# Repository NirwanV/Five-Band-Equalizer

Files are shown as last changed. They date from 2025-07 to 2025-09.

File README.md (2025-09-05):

# 🎶 5-Band Analog Equalizer  
  
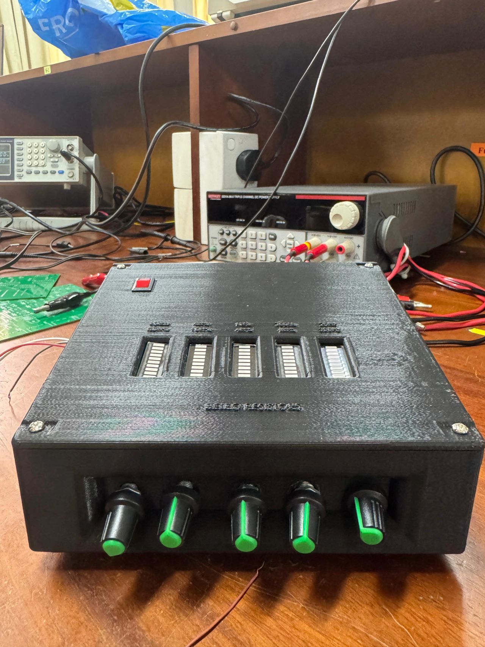
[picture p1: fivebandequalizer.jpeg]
CAD
  

A **5-Band Analog Audio Equalizer** built from scratch as part of an **Analog Design Project**.  
This project explores **audio signal processing using analog circuitry**, enabling users to shape and enhance sound across five distinct frequency bands.  

---

## ✨ Features  

- **5-Band Frequency Control**  
  - 60–300 Hz (Low)  
  - 300–1000 Hz (Low-Mid)  
  - 1–4 kHz (Mid)  
  - 4–10 kHz (High-Mid)  
  - 10–20 kHz (High)  

- **Precision Signal Processing**  
  - Buffered input audio  
  - Bandpass filtering for each frequency range  
  - Summed output for balanced and clean audio  

- **Audio Performance**  
  - Designed with **TL072 Op-Amps** for low-noise, high-fidelity sound  

- **User-Friendly Design**  
  - **LED indicators** for real-time band monitoring  
  - Custom **enclosure design** for a sleek, professional finish  

---

## 🛠️ Technologies & Tools  

- **Circuit Simulation & Design:** LTSpice / Multisim  
- **Prototyping:** Breadboard implementation  
- **PCB Design:** Altium Designer  
- **Enclosure Design:** SolidWorks / CAD tools  
- **Components:** TL072 Op-Amps, Resistors, Capacitors, Potentiometers, LEDs  

---

## 🚀 Getting Started  

1. **Build the Circuit** – Assemble the bandpass filters and buffering stages on a breadboard.  
2. **Test the Frequency Response** – Use a signal generator + oscilloscope to verify band cutoffs.  
3. **Integrate LED Indicators** – Connect LED driver circuit for real-time monitoring.  
4. **Assemble PCB & Enclosure** – Transfer the circuit to PCB and fit into the designed enclosure.  
5. **Enjoy Your Music!** 🎶  

---

## 📂 Repository Structure  

```bash
├── schematics/        # Circuit diagrams and LTSpice/Multisim files
├── pcb_layout/        # PCB design files (Altium)
├── enclosure/         # CAD models and renders
├── docs/              # Reports, notes, frequency response graphs
└── README.md          # Project documentation

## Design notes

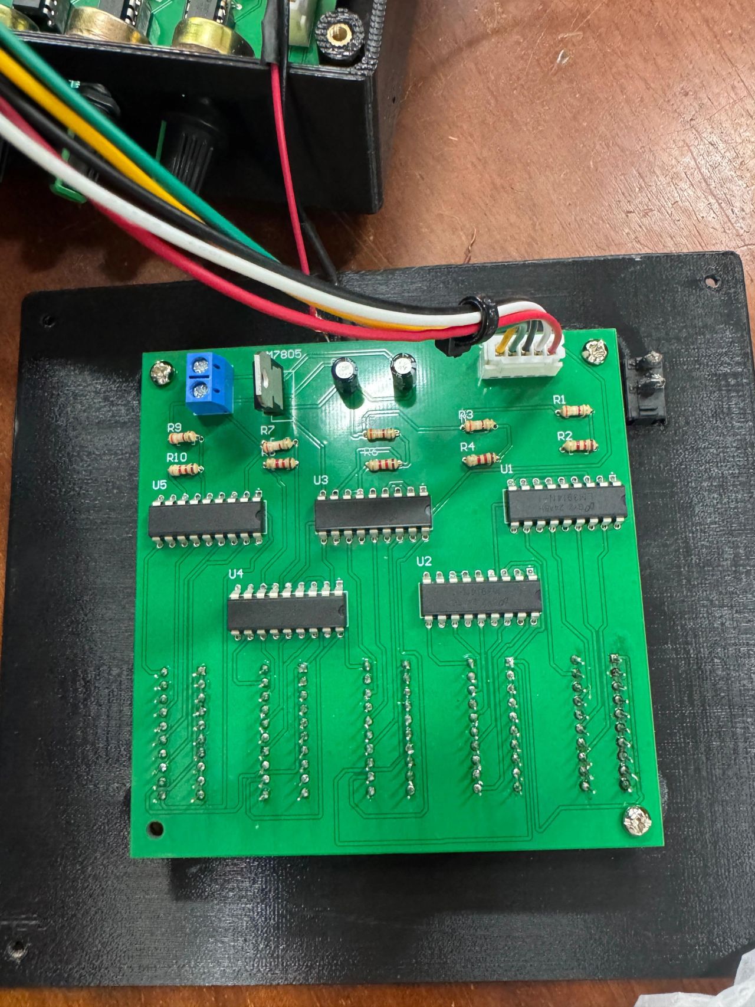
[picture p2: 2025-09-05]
LED_Bar_circuit_PCB.jpeg

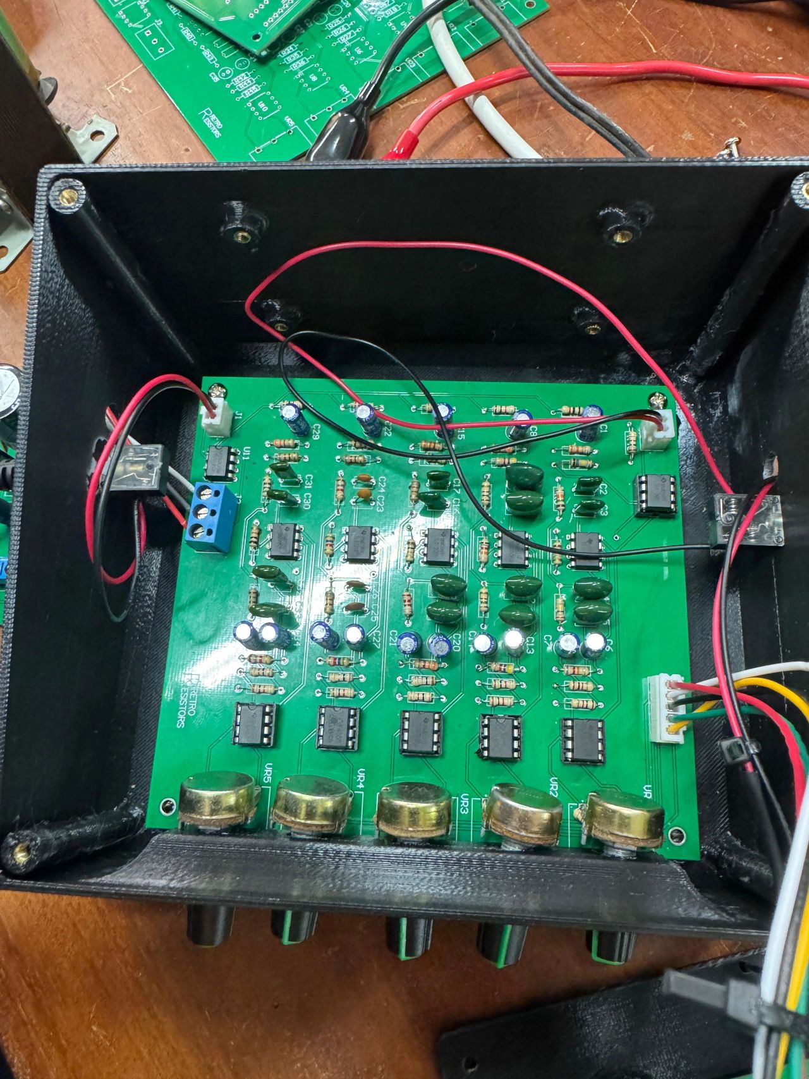
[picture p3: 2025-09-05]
FilterCircuitPCB.jpeg

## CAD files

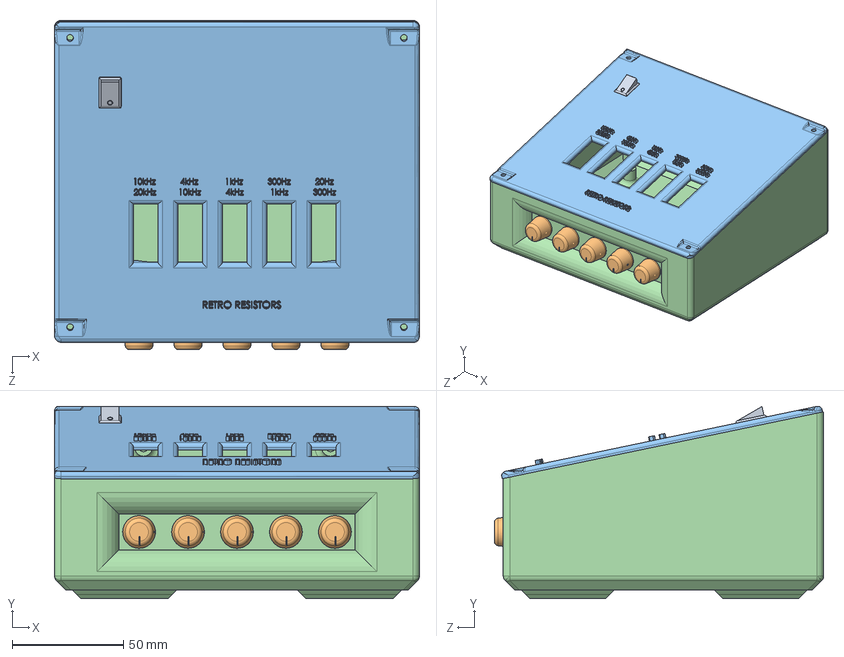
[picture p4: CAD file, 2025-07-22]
Version1/Solidworks/Assem1.11.SLDASM
164.0 x 86.5 x 148.0 mm
lab low
lab above
knob x 5
SWITCH

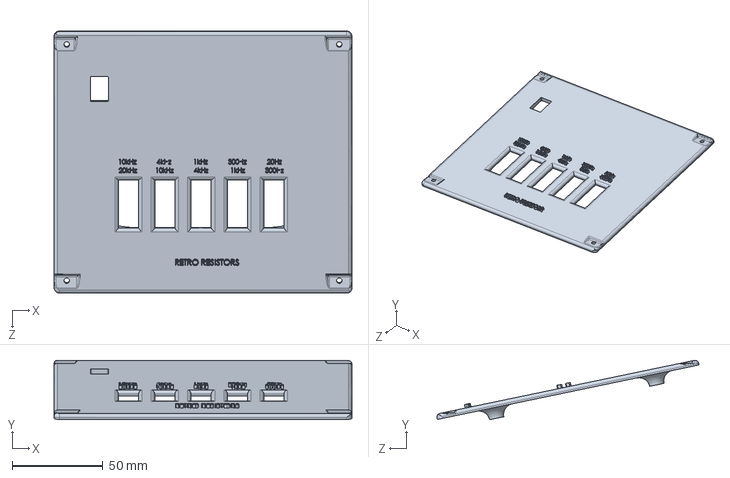
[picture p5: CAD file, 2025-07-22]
Version1/Solidworks/lab above.SLDPRT
164.0 x 32.7 x 144.2 mm

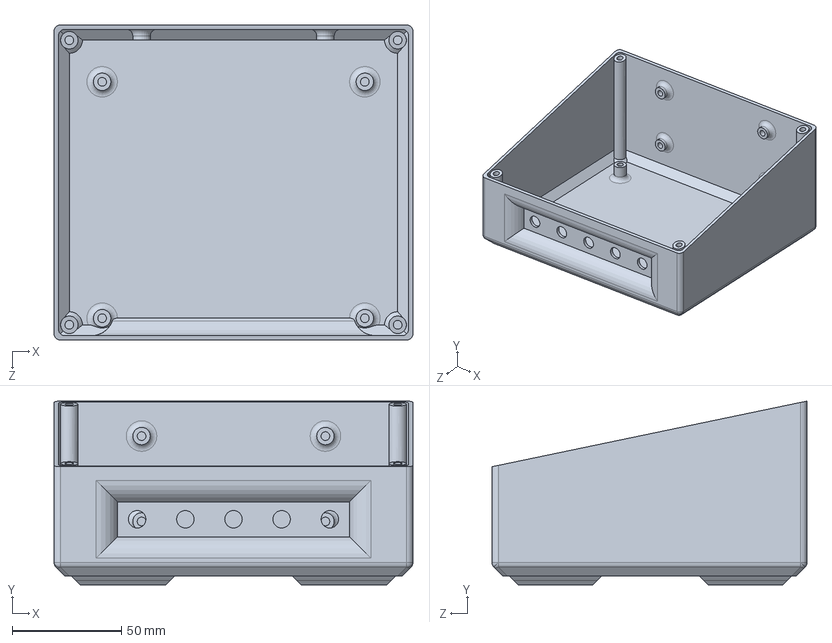
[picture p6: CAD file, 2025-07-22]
Version1/Solidworks/lab low.SLDPRT
164.0 x 84.0 x 144.0 mm

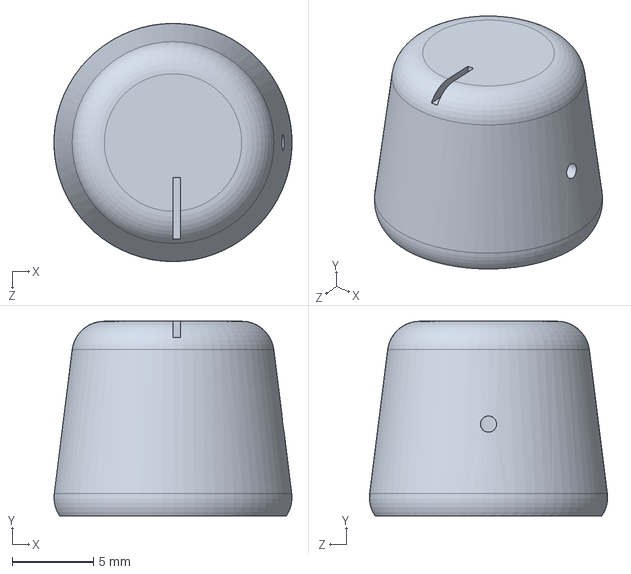
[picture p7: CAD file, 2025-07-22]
Version1/Solidworks/knob.SLDPRT
14.7 x 12.0 x 14.7 mm

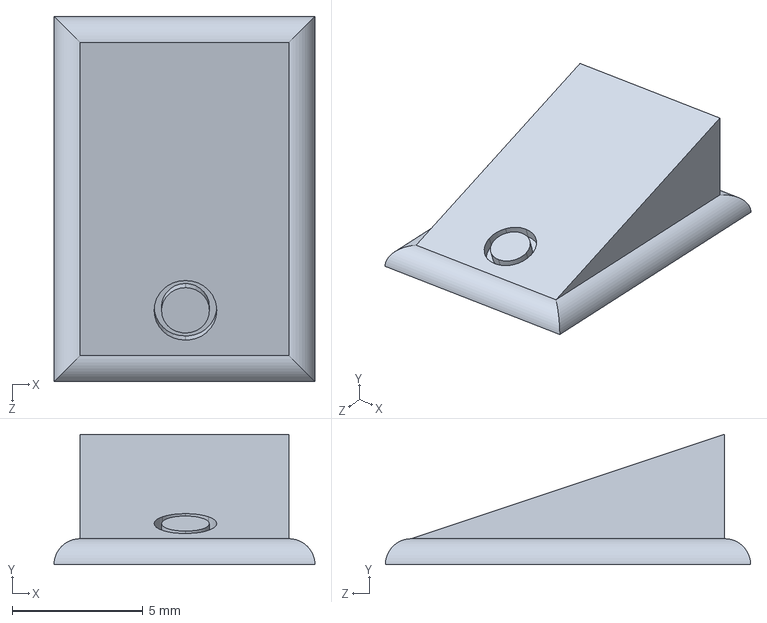
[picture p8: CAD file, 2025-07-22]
Version1/Solidworks/SWITCH.SLDPRT
10.0 x 5.00 x 14.0 mm

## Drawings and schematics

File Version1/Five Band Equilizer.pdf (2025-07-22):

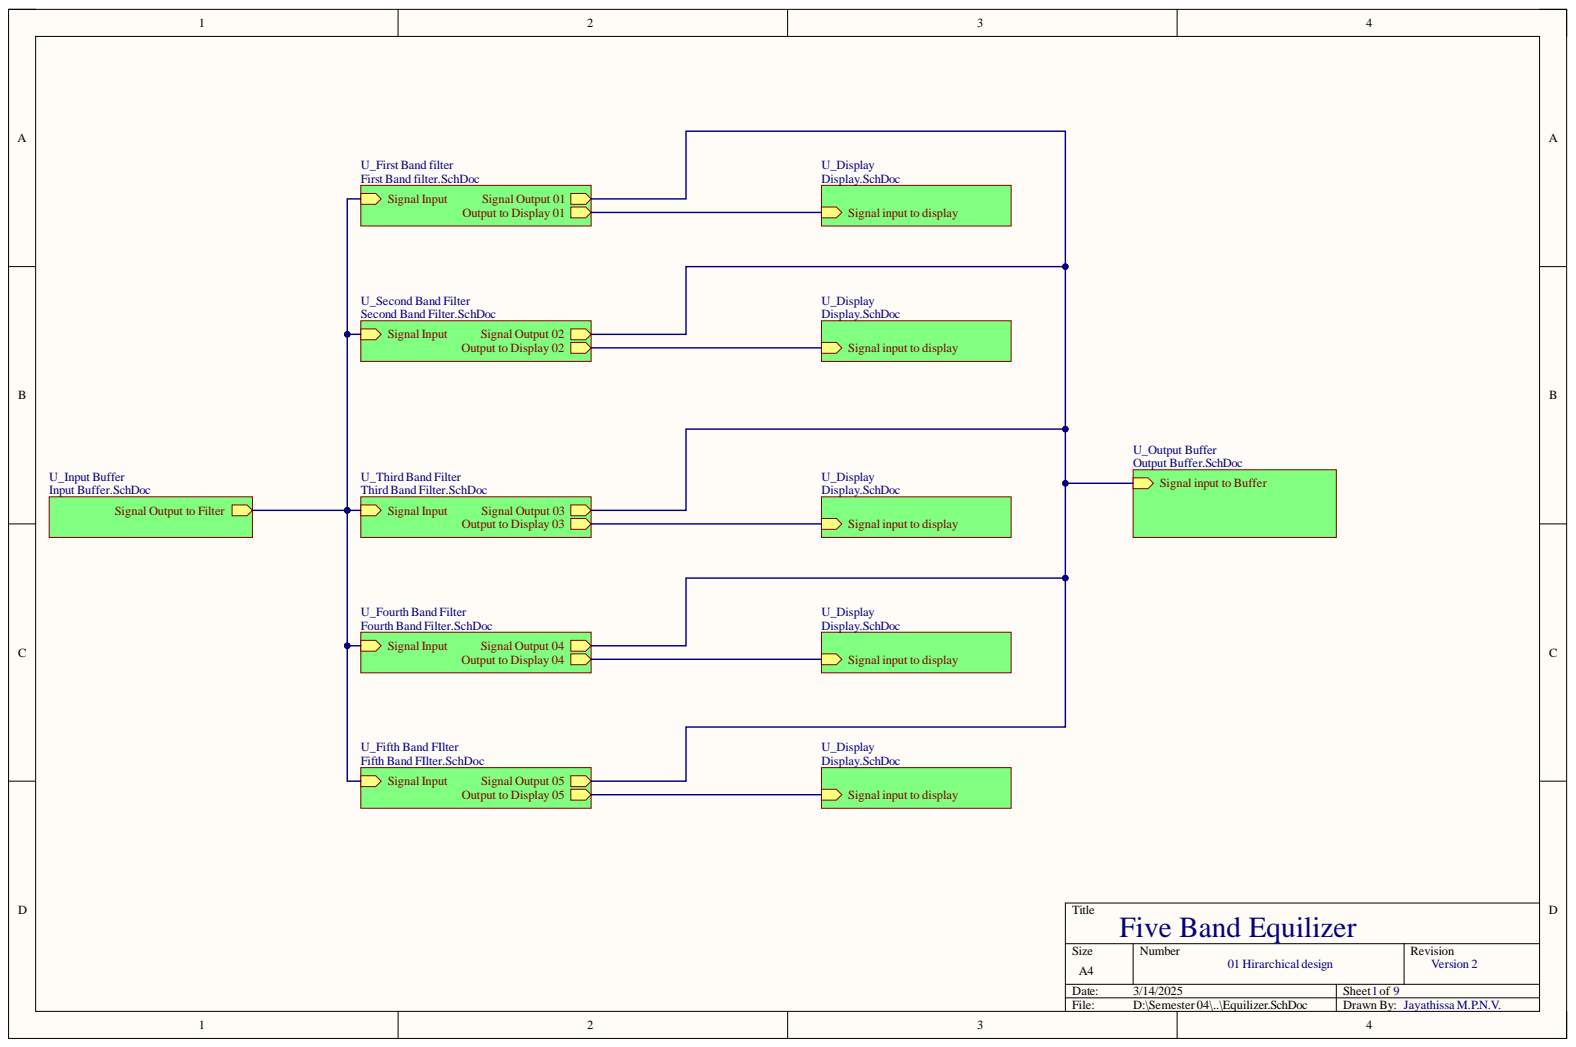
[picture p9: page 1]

U_First Band filter
First Band filter.SchDoc
Signal Input

Signal input to display

U_Second Band Filter
Second Band Filter.SchDoc

U_Output Buffer
Output Buffer.SchDoc
Signal input to Buffer

U_Third Band Filter
Third Band Filter.SchDoc

Signal Output to Filter

U_Fourth Band Filter
Fourth Band Filter.SchDoc

U_Fifth Band FIlter
Fifth Band FIlter.SchDoc

Size A4 | Number 01 Hirarchical design | Revision Version 2

Date: 3/14/2025 | Sheet of 1 9
File: D:\Semester 04\..\Equilizer.SchDoc | Drawn By: Jayathissa M.P.N.V.

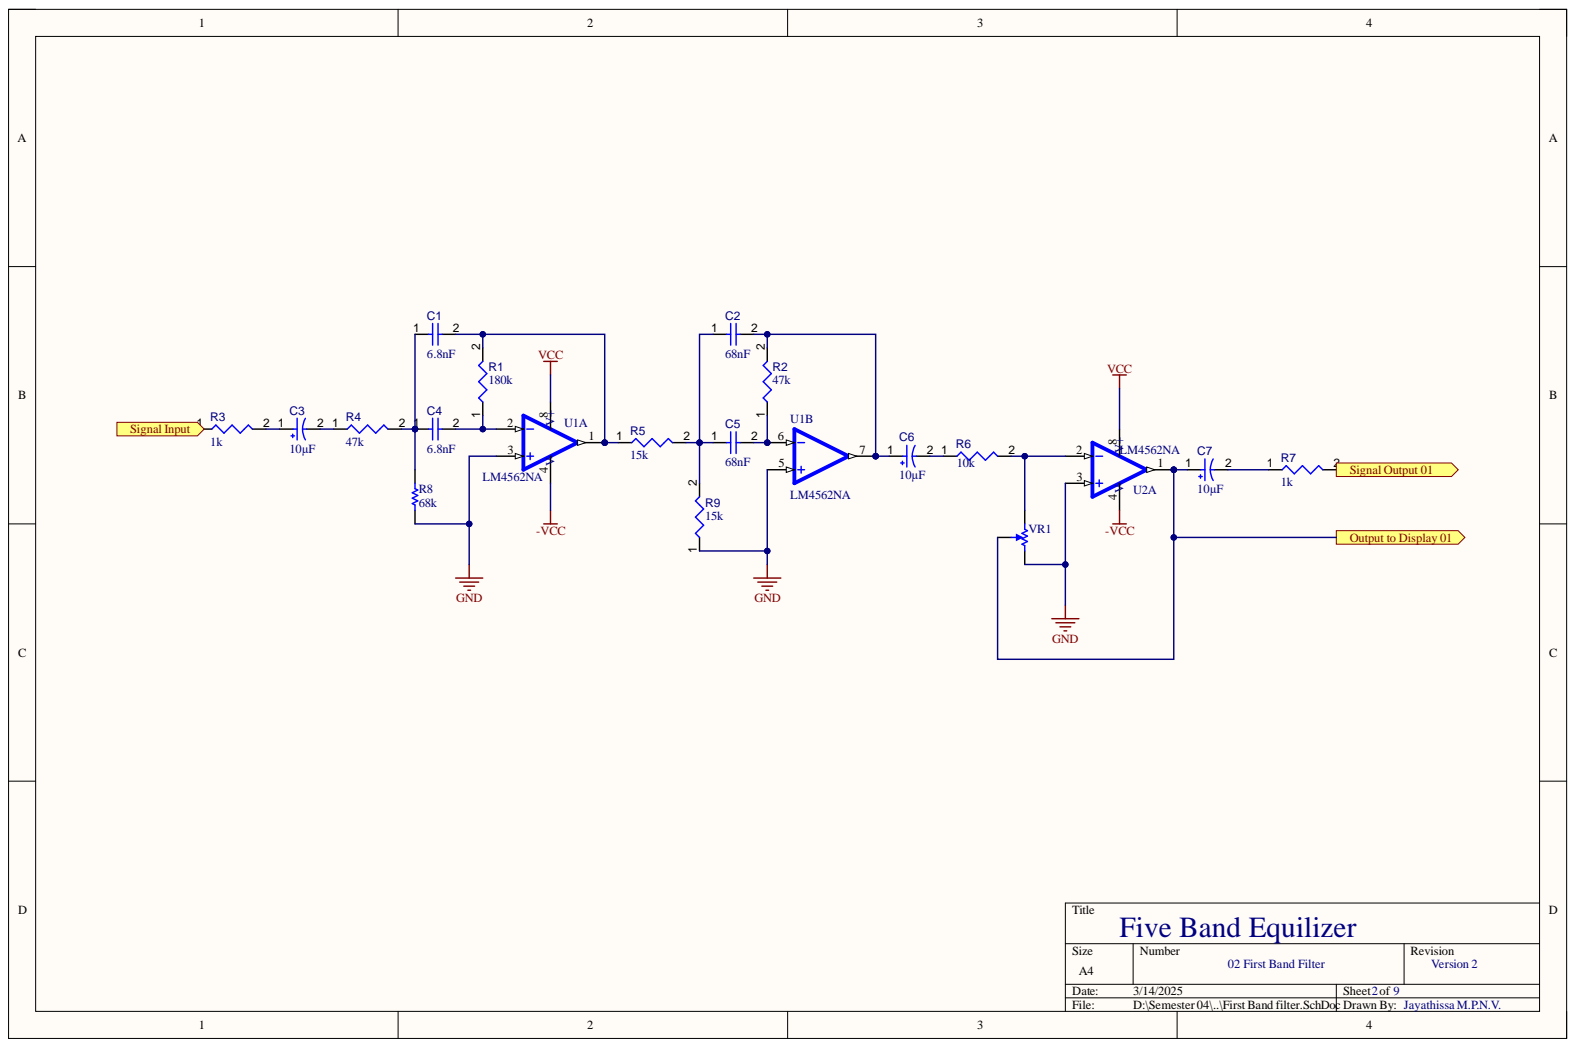
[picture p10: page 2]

Siz e A4 | Numb e r 02 First B and Filte r | R evisio n Ve rsion 2

Da te : 3/14/202 5 | She et of 2 9
File : D:\S emeste r 04\. .\First B and filte r . S c hD o | c Dr awn B y : Jayathissa M. P. N . V.

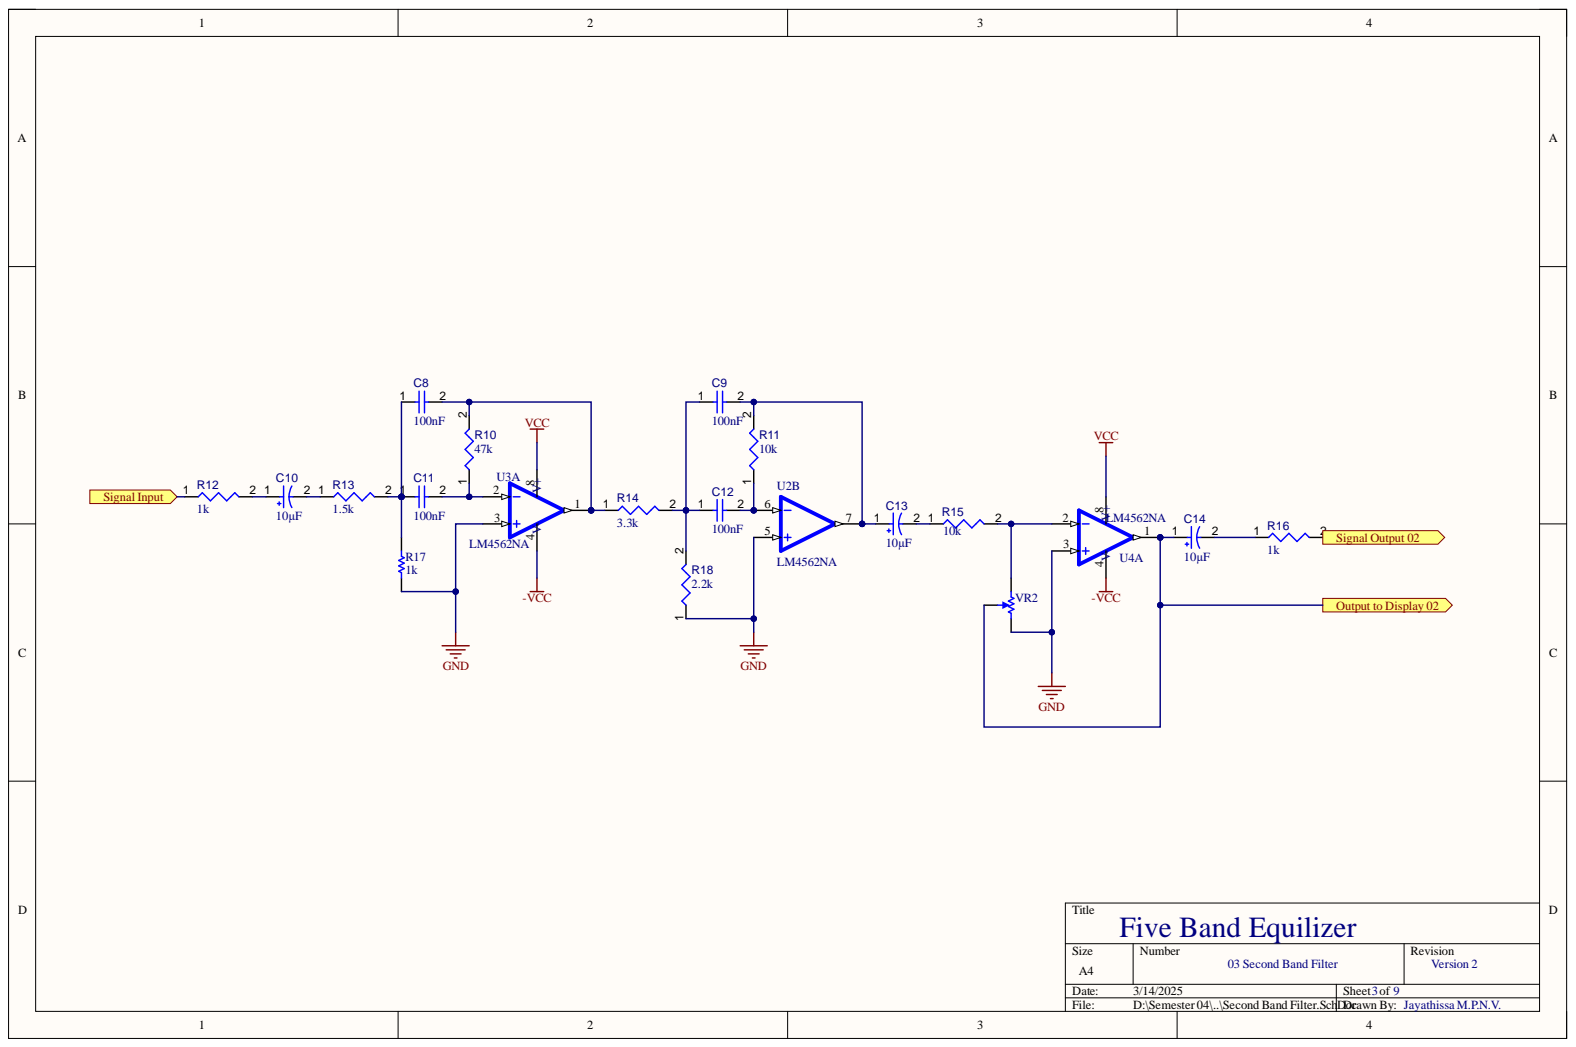
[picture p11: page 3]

Siz e A4 | Numb e r 03 S e cond B and Filte r | R evisio n Ve rsion 2

Da te : 3/14/202 5 | She et of 3 9
File : D:\S emeste r 04\. .\S e cond B and Filte r . S c hDDr oc | awn B y : Jayathissa M. P. N . V.

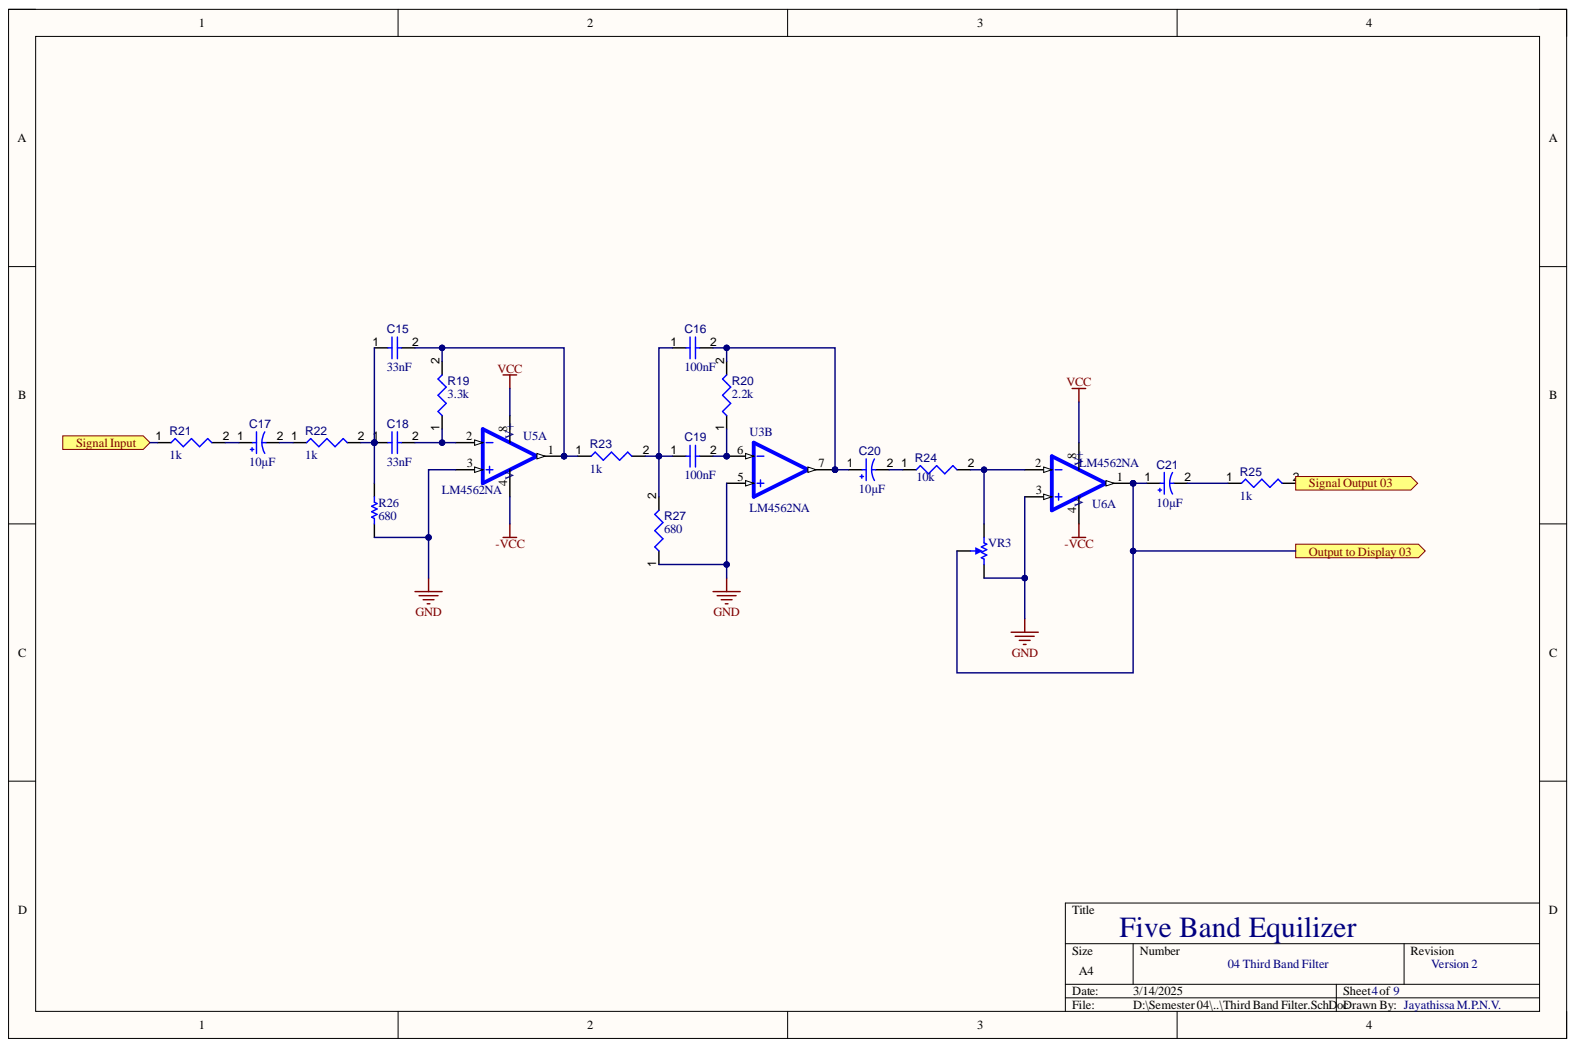
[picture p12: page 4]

Siz e A4 | Numb e r 04 Third B and Filte r | R evisio n Ve rsion 2

Da te : 3/14/202 5 | She et of 4 9
File : D:\S emeste r 04\. .\Third B and Filte r . S c hD | o cDr awn B y : Jayathissa M. P. N . V.

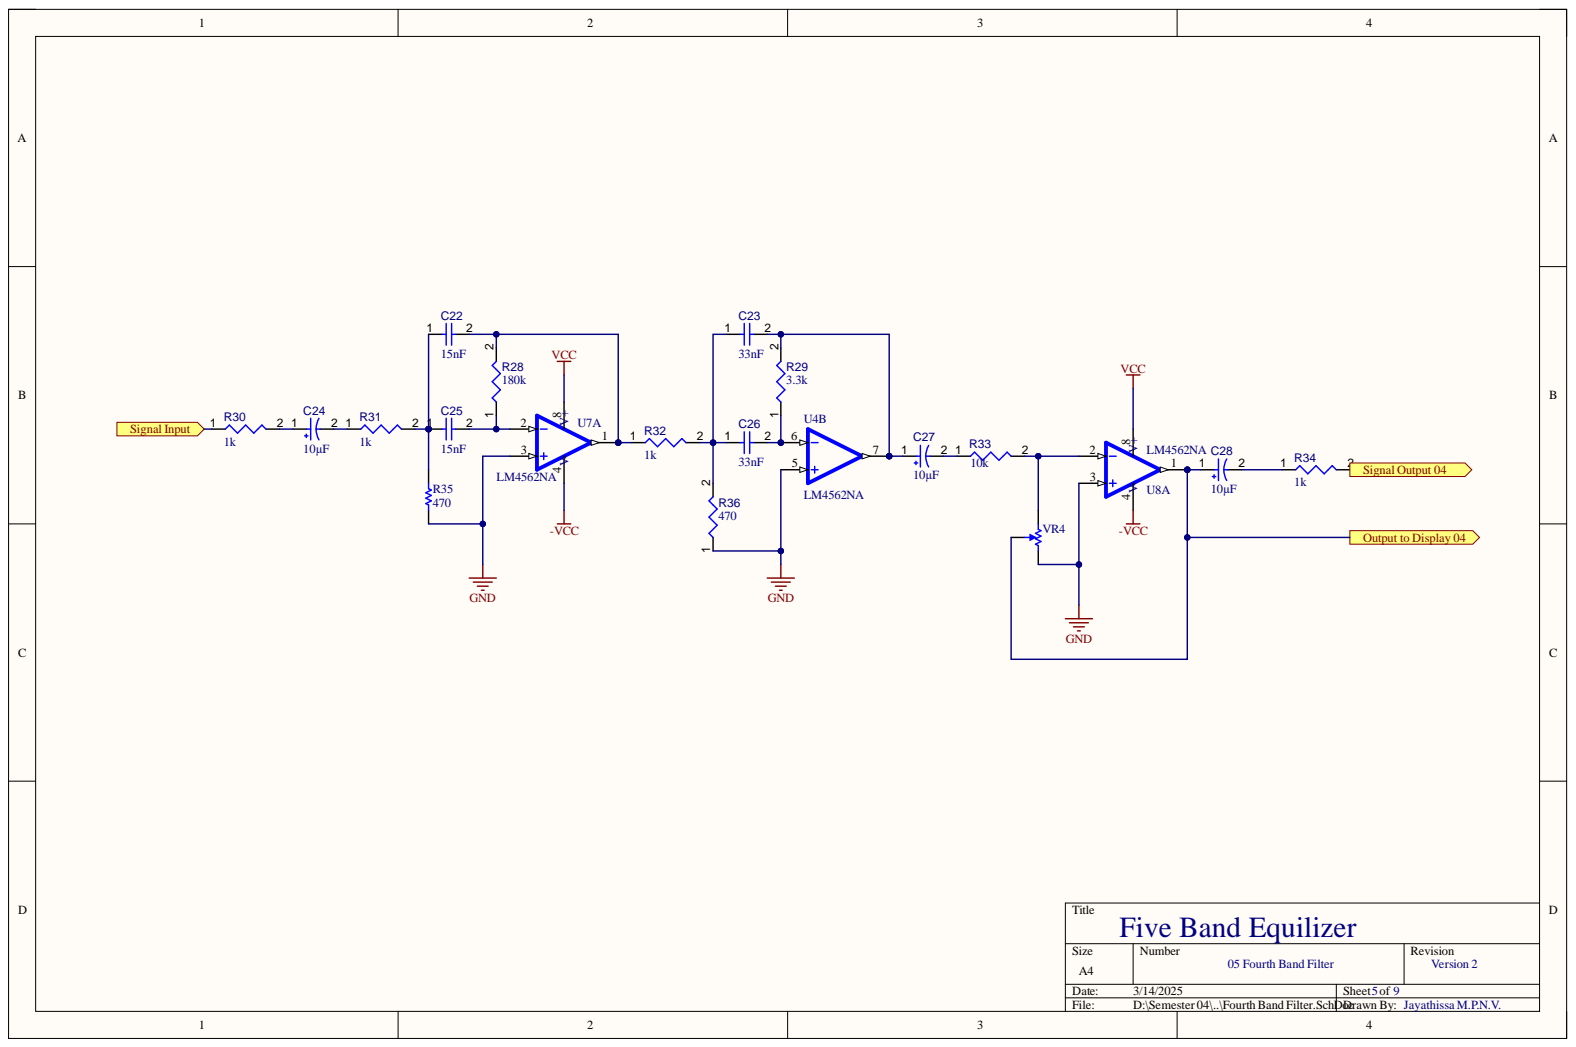
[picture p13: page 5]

Siz e A4 | Numb e r 05 Fourth B and Filte r | R evisio n Ve rsion 2

Da te : 3/14/202 5 | She et of 5 9
File : D:\S emeste r 04\. .\Fourth B and Filte r . S c hD | oDrc awn B y : Jayathissa M. P. N . V.

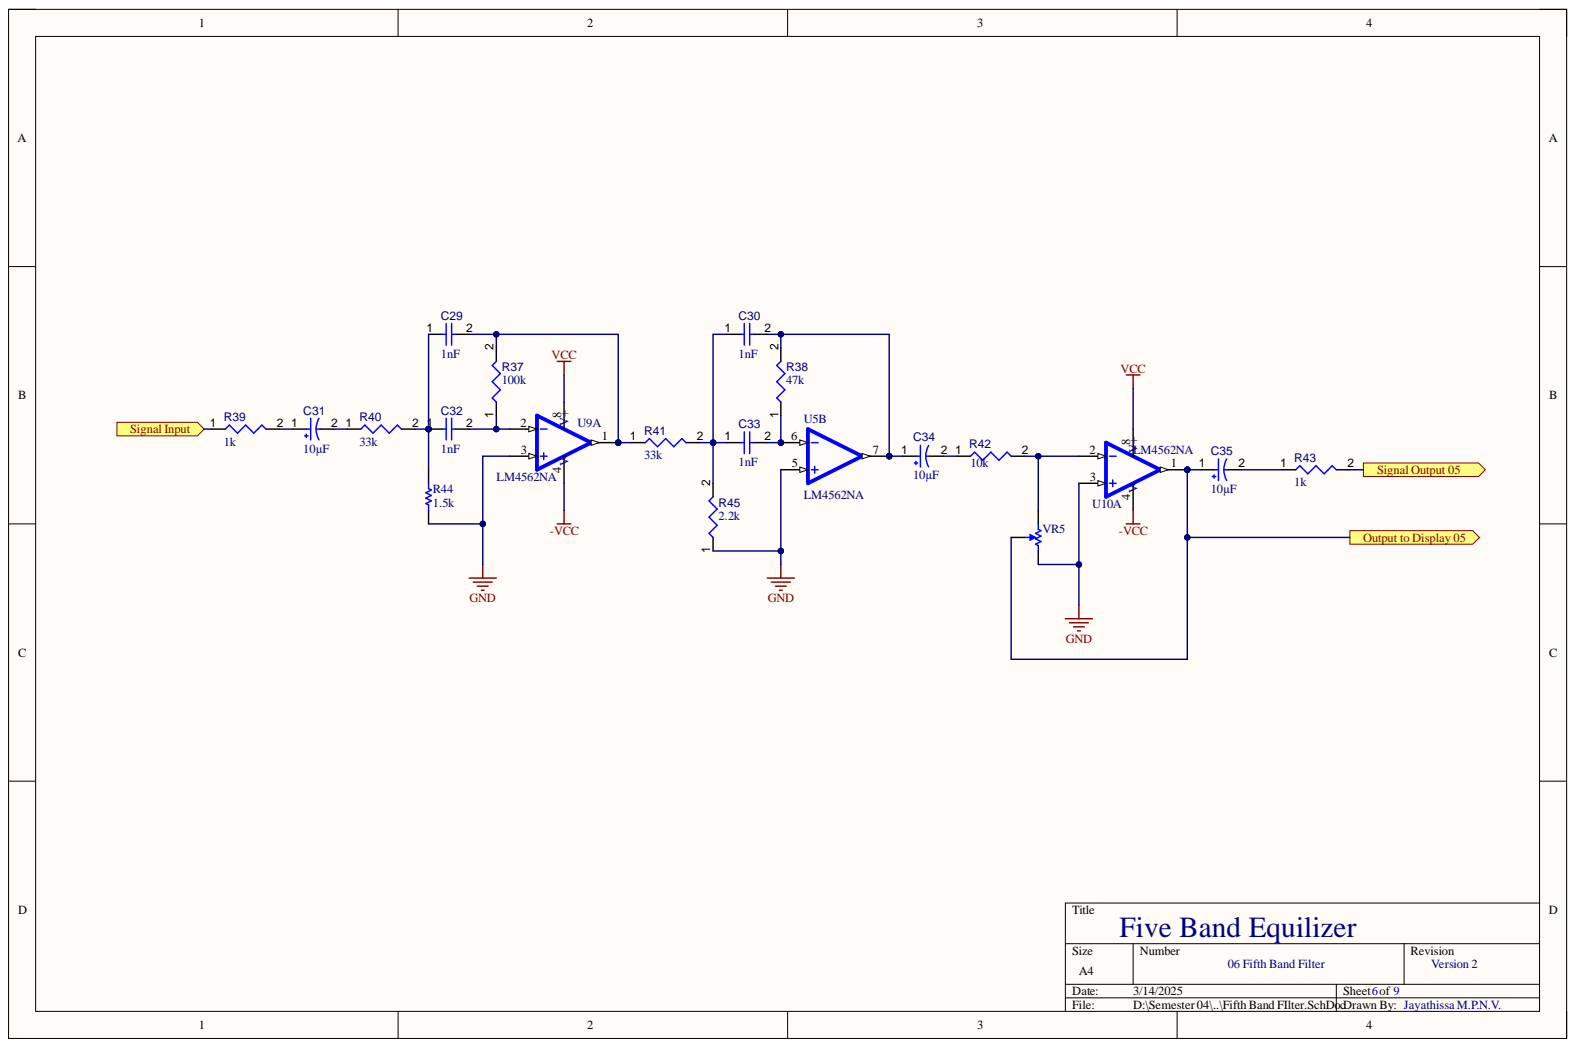
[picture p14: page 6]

Siz e A4 | Numb e r 06 Fifth B and Filte r | R evisio n Ve rsion 2

Da te : 3/14/202 5 | She et of 6 9
File : D:\S emeste r 04\. .\Fifth B and F Ilte r . S c hD | o cDr awn B y : Jayathissa M. P. N . V.

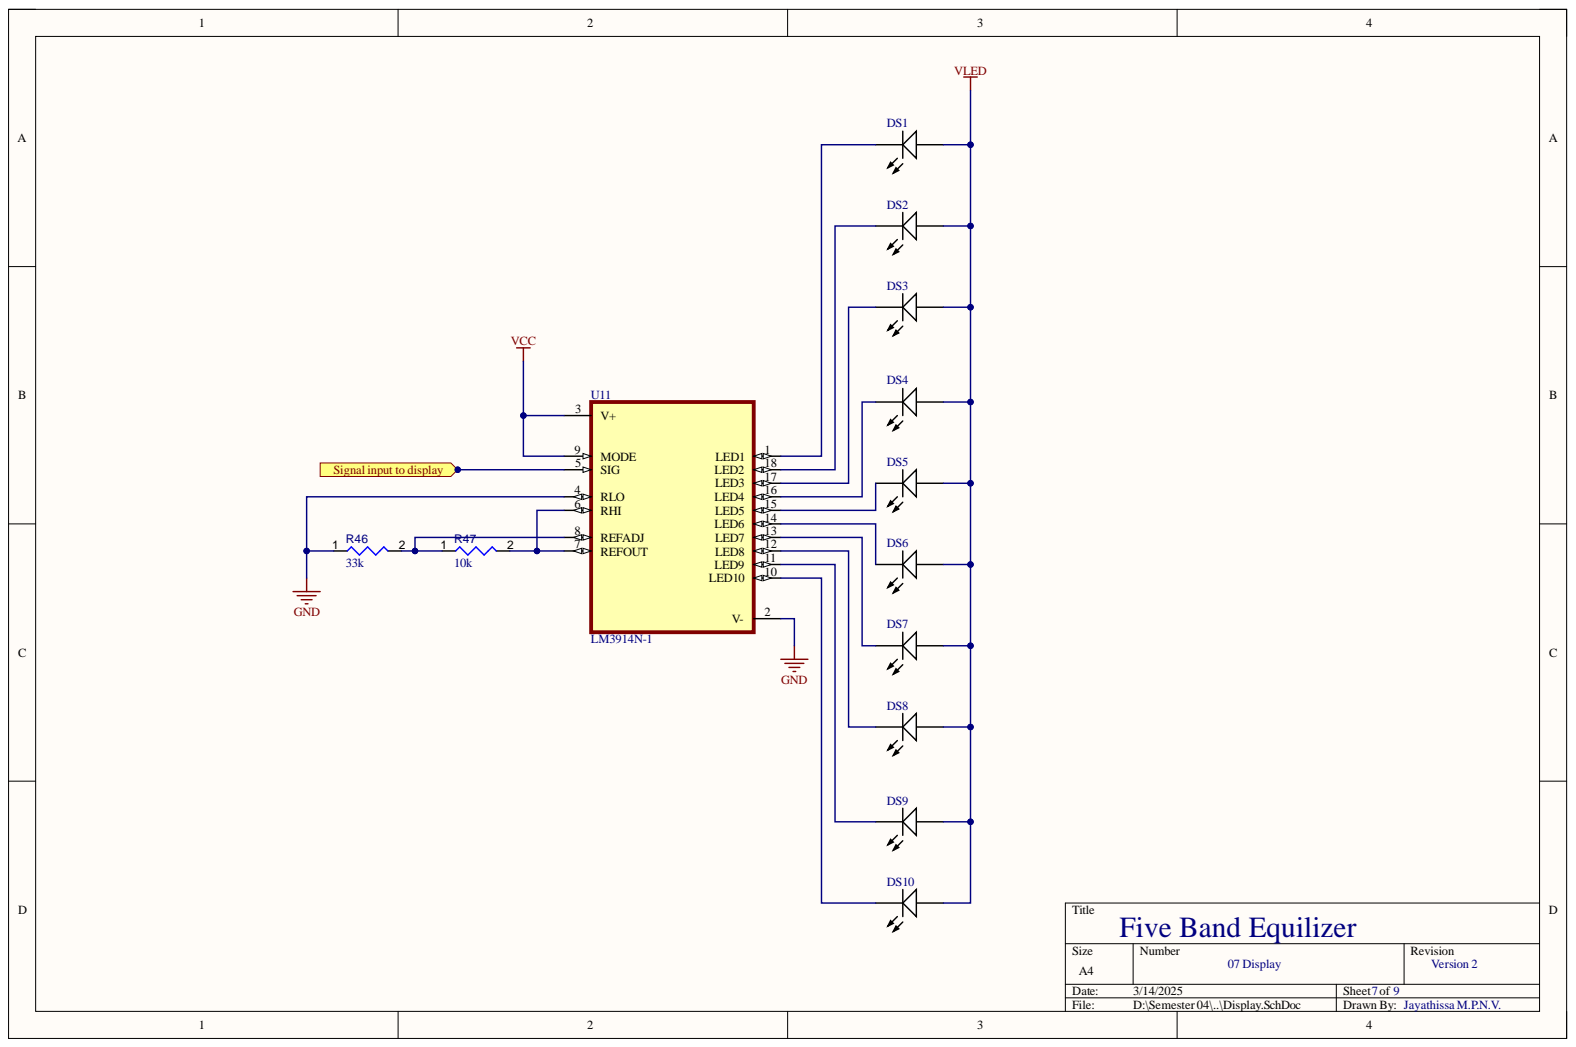
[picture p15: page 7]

MODE 9

Signal input to display

33k | | RHI 6

Size A4 | Number 07 Display | Revision Version 2

Date: 3/14/2025 | Sheet of 7 9
File: D:\Semester 04\..\Display.SchDoc | Drawn By: Jayathissa M.P.N.V.

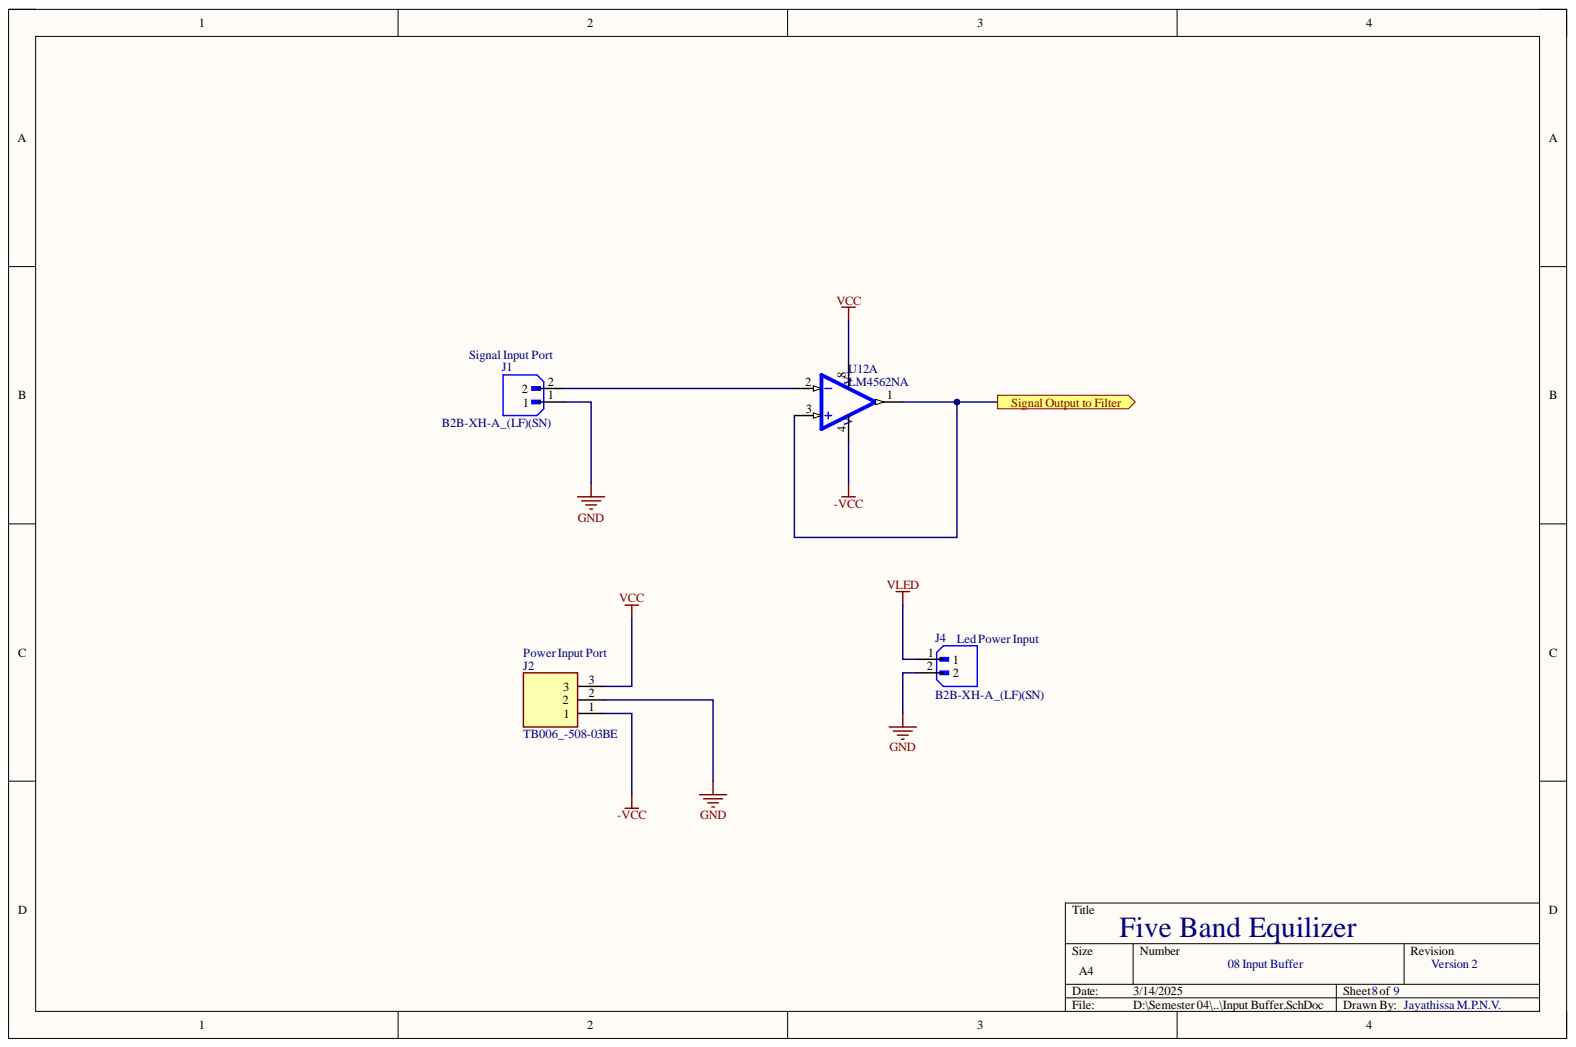
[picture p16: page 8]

Signal Output to Filter

Size A4 | Number 08 Input Buffer | Revision Version 2

Date: 3/14/2025 | Sheet of 8 9
File: D:\Semester 04\..\Input Buffer.SchDoc | Drawn By: Jayathissa M.P.N.V.

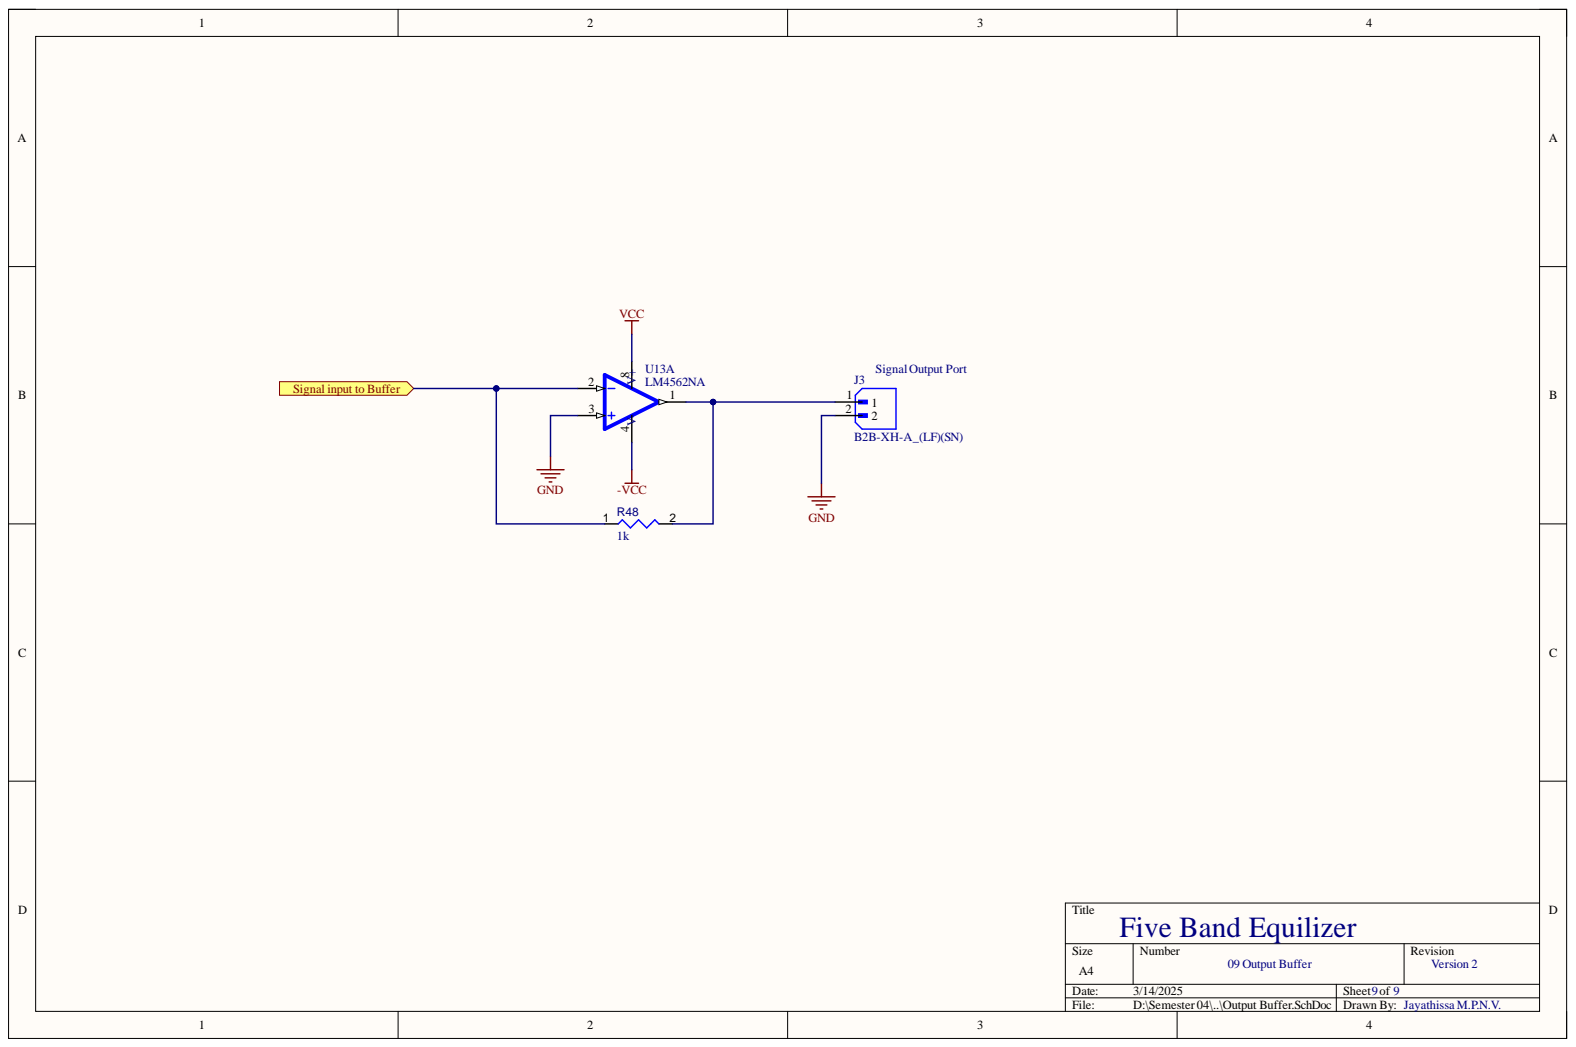
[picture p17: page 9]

Signal input to Buffer

Size A4 | Number 09 Output Buffer | Revision Version 2

Date: 3/14/2025 | Sheet of 9 9
File: D:\Semester 04\..\Output Buffer.SchDoc | Drawn By: Jayathissa M.P.N.V.

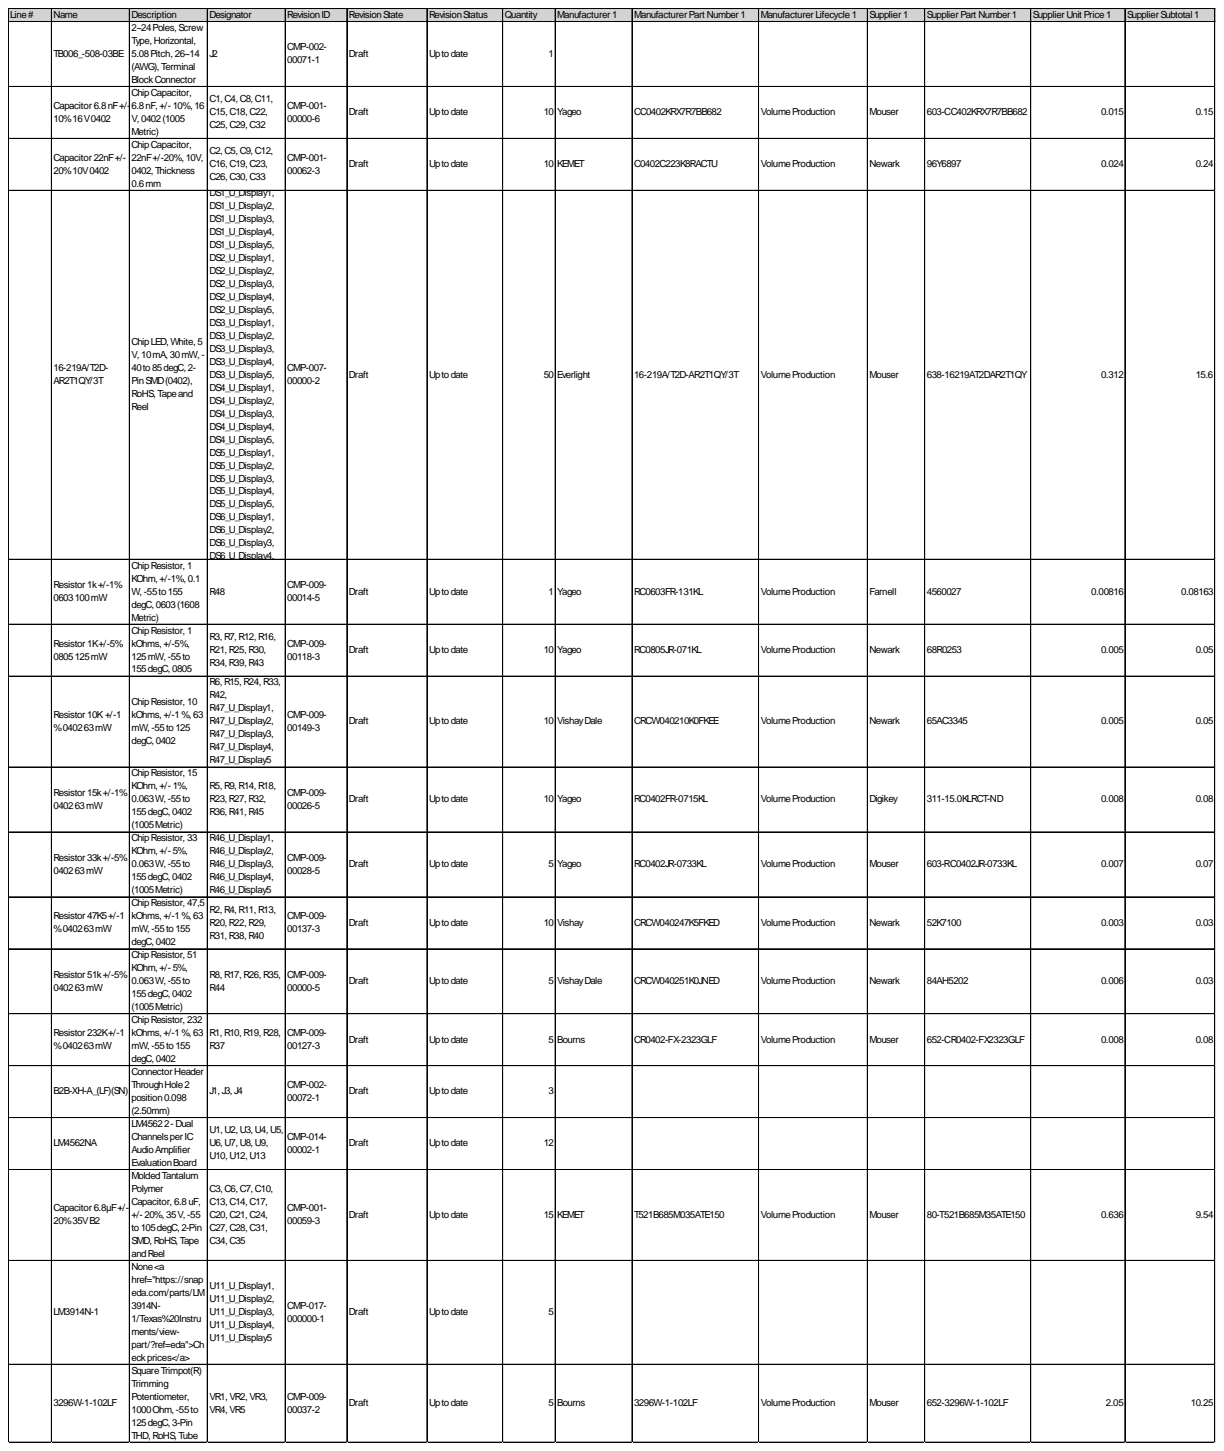
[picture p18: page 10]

Line# | Name | Description | Designator | RevisionID | RevisionState | RevisionStatus | Quantity | Manufacturer 1 | Manufacturer Part Number 1 | Manufacturer Lifecycle 1 | Supplier 1 | Supplier Part Number 1 | Supplier Unit Price 1 | Supplier Subtotal 1

TB006_-508-03BE | 2~24Poles, Screw Type, Horizontal, 5.08Pitch, 26~14 (AWG), Terminal BlockConnector | J2 | CMP-002-00071-1 | Draft | Uptodate | 1

Capacitor 6.8nF+/-10%16V0402 | ChipCapacitor, 6.8nF, +/- 10%, 16 V, 0402(1005 Metric) | C1, C4, C8, C11, C15, C18, C22, C25, C29, C32 | CMP-001-00000-6 | Draft | Uptodate | 10 | Yageo | CC0402KRX7R7BB682 | VolumeProduction | Mouser | 603-CC402KRX7R7BB682 | 0.015 | 0.15

Capacitor 22nF+/-20%10V0402 | ChipCapacitor, 22nF+/-20%, 10V, 0402, Thickness 0.6mm | C2, C5, C9, C12, C16, C19, C23, C26, C30, C33 | CMP-001-00062-3 | Draft | Uptodate | 10 | KEMET | C0402C223K8RACTU | VolumeProduction | Newark | 96Y6897 | 0.024 | 0.24

16-219A/T2D-AR2T1QY/3T | ChipLED, White, 5 V, 10mA, 30mW, -40to85degC, 2-PinSMD(0402), RoHS, Tapeand Reel | DS1_U_Display1, DS1_U_Display2, DS1_U_Display3, DS1_U_Display4, DS1_U_Display5, DS2_U_Display1, DS2_U_Display2, DS2_U_Display3, DS2_U_Display4, DS2_U_Display5, DS3_U_Display1, DS3_U_Display2, DS3_U_Display3, DS3_U_Display4, DS3_U_Display5, DS4_U_Display1, DS4_U_Display2, DS4_U_Display3, DS4_U_Display4, DS4_U_Display5, DS5_U_Display1, DS5_U_Display2, DS5_U_Display3, DS5_U_Display4, DS5_U_Display5, DS6_U_Display1, DS6_U_Display2, DS6_U_Display3, DS6_U_Display4, | CMP-007-00000-2 | Draft | Uptodate | 50 | Everlight | 16-219A/T2D-AR2T1QY/3T | VolumeProduction | Mouser | 638-16219AT2DAR2T1QY | 0.312 | 15.6

Resistor 1k+/-1% 0603100mW | ChipResistor, 1 KOhm, +/-1%, 0.1 W, -55to155 degC, 0603(1608 Metric) | R48 | CMP-009-00014-5 | Draft | Uptodate | 1 | Yageo | RC0603FR-131KL | VolumeProduction | Farnell | 4560027 | 0.00816 | 0.08163

Resistor 1K+/-5% 0805125mW | ChipResistor, 1 kOhms, +/-5%, 125mW, -55to 155degC, 0805 | R3, R7, R12, R16, R21, R25, R30, R34, R39, R43 | CMP-009-00118-3 | Draft | Uptodate | 10 | Yageo | RC0805JR-071KL | VolumeProduction | Newark | 68R0253 | 0.005 | 0.05
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
